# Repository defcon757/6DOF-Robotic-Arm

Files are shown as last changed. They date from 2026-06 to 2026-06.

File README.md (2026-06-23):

# ARM-6 — 6DOF Wi-Fi Controlled Robotic Arm

A fully remote-controlled, 6-degree-of-freedom robotic arm with live ESP32-CAM video feedback, controlled through a locally hosted Python/Flask web GUI over Wi-Fi.

Built by **Aidan Hernandez** — ENG GEN 101, Spring 2026.

---

## 📸 System Overview

```
Operator (Browser GUI)
        │
        ▼
Python Flask Server (Laptop)
   ├── Sends motion commands → ESP32 (ARM CONTROLLER)
   │                                   └── PCA9685 → 7 motors
   └── Streams video from  ← ESP32-CAM (CAMERA)
```

The system uses **two separate ESP32 boards**:
- `esp32_arm_controller` — receives JSON commands over HTTP, drives all 7 motors via a PCA9685 servo driver
- `esp32_cam_streamer` — streams MJPEG video from the OV2640 camera sensor over HTTP

---

## 🤖 Hardware

| Component | Qty | Notes |
|---|---|---|
| ESP32 Dev Board | 1 | Arm controller |
| ESP32-CAM (AI Thinker) | 1 | Video stream |
| PCA9685 16-Channel Servo Driver | 1 | I2C, drives all motors |
| REV Robotics HD Hex Motor (Continuous) | 3 | Base (×1), Shoulder (×2, mirrored) |
| MG996R Servo | 2 | Elbow, Wrist U/D |
| Micro Servo | 2 | Wrist Rotation, Claw |
| 5V 20A Power Supply | 1 | Powers motors + electronics |
| 3D Printed Arm Structure | — | See `/cad/stl/` |

### Motor Channel Map (PCA9685)

| Channel | Joint | Type |
|---|---|---|
| 0 | Base | Continuous motor |
| 1 | Left Shoulder | Continuous motor |
| 2 | Right Shoulder | Continuous motor (mirrored) |
| 3 | Elbow | Positional servo |
| 4 | Wrist Up/Down | Positional servo |
| 5 | Wrist Rotation | Positional servo |
| 6 | Claw | Positional servo |

### PWM Reference (50 Hz)

| Value | Meaning |
|---|---|
| `102` | Full reverse (continuous motors) |
| `307` | Stop / center (CONT_STOP) |
| `512` | Full forward (continuous motors) |
| `102–512` | Mapped from 0°–270° (positional servos) |

---

## 🗂 Repository Structure

```
arm6-robot/
├── firmware/
│   ├── esp32_arm_controller/
│   │   └── esp32_arm_controller.ino   # ESP32 arm command receiver
│   └── esp32_cam_streamer/
│       └── esp32_cam_streamer.ino     # ESP32-CAM MJPEG stream server
│
├── server/
│   ├── app.py                         # Flask routes
│   ├── arm_controller.py              # RobotArm class — state + HTTP send
│   ├── arm_sequence.py                # Scripted sequences (wave, scan, pickup…)
│   ├── config.py                      # IP addresses
│   ├── templates/
│   │   └── index.html                 # Jinja2 dashboard template
│   └── static/
│       ├── script.js                  # Hold-to-move button logic, status polling
│       └── style.css                  # Dark dashboard theme
│
├── cad/
│   └── stl/                           # 3D-printable arm parts (upload .stl files here)
│       ├── Arm_Parts.stl
│       ├── Base_Parts.stl
│       ├── Claw_Parts.stl
│
├── docs/
│   ├── wiring_diagram.md
│   ├── setup_guide.md
│   └── images/                        # Photos / diagrams (upload here)
│
├── requirements.txt
├── .gitignore
└── README.md
```

---

## ⚡ Quick Start

### 1. Configure IPs

Edit `server/config.py`:
```python
ARM_IP    = "192.168.x.xxx"   # IP of the ESP32 arm controller
CAMERA_IP = "192.168.x.xxx"   # IP of the ESP32-CAM
```

### 2. Flash the ESP32 boards

- Open `firmware/esp32_arm_controller/esp32_arm_controller.ino` in Arduino IDE
- Open `firmware/esp32_cam_streamer/esp32_cam_streamer.ino` in Arduino IDE
- Update `ssid` and `password` in **both** sketches
- Flash each to the correct board (see [Setup Guide](docs/setup_guide.md))

### 3. Install Python dependencies

```bash
pip install -r requirements.txt
```

### 4. Start the Flask server

```bash
cd server
python app.py
```

### 5. Open the GUI

Navigate to `http://localhost:5000` in any browser on the same network.

---

## 🎮 Controls

### Continuous Motors (Base, Shoulder)
Hold a direction button — each tick nudges the PWM pulse by ±8 counts. Releasing the button sends a stop command that resets the pulse to `307` (CONT_STOP).

### Positional Servos (Elbow, Wrist U/D, Wrist Rotation, Claw)
Hold a direction button — each tick moves the servo ±15°. Range is clamped to 0°–270°. A CENTER button snaps the joint to 135°.

### Preset Sequences (CLI — `arm_sequence.py`)
Run standalone from the command line, bypasses Flask and sends directly to the ESP32:

```bash
cd server
python arm_sequence.py
```

| Key | Sequence |
|---|---|
| `1` | Wave |
| `2` | Scan (base sweep) |
| `3` | Pickup simulation |
| `4` | Wrist display |
| `5` | Full showcase |
| `6` | Idle loop |
| `0` | Home all joints |

---

## 📡 API Reference

All endpoints are POST (except `/status`), expect and return JSON.

| Route | Method | Body | Description |
|---|---|---|---|
| `/servo` | POST | `{name, delta}` | Relative servo move |
| `/servo_set` | POST | `{name, angle}` | Absolute servo position |
| `/motor_nudge` | POST | `{name, delta}` | Nudge continuous motor pulse |
| `/motor_stop` | POST | `{name}` | Stop a motor (reset to 307) |
| `/home` | POST | — | Center all joints |
| `/stop` | POST | — | Emergency stop all motors |
| `/status` | GET | — | Returns current servo angles + motor pulses |

Valid `name` values: `base`, `shoulder`, `elbow`, `wrist_ud`, `wrist_rotate`, `claw`

---

## 🖨 CAD / 3D Printing

The arm was designed in **Onshape**. All printable parts are in `cad/stl/`. Recommended print settings:
- Material: PLA or PETG
- Infill: 20–30%
- Supports: Required for base only

## ⚠️ Known Limitations

- Requires a stable 2.4 GHz Wi-Fi network (ESP32 does not support 5 GHz)
- Continuous motors use open-loop control — no positional feedback
- Power supply must be external (5V, ≥10A recommended for full motion)
- Camera stream is low resolution (160×120) to reduce latency

---

## 📄 License

MIT License — free to use, modify, and build upon.

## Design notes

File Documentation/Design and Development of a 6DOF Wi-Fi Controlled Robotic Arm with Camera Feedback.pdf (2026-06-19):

Hernandez 1

Design and Development of a 6DOF Wi-Fi Controlled Robotic Arm with Camera Feedback

Aidan Hernandez

Professor Parvaneh Ghaforyfard

ENG GEN 101

29 May 2026

Introduction

The purpose of this project was to design and build a robotic arm that could be controlled

remotely through Wi-Fi via a GUI and stream live camera feedback. The project was a

combination of mechanical design, mechatronics, and software development into a single

working prototype. The final system was designed using the engineering design process and is

intended to solve the problem of taking off a finished 3D printed object from the print bed so I

can remotely print another object while being away from home. However, I have applied a real-

world use case of technology to solve the problem of inspecting dangerous equipment by making

this process remote and automated.

Engineering Design Process

The engineering design process began by identifying the problem. In many real-world

situations, a person may need to move an object, inspect a space, or interact with equipment

without standing directly next to it due to a variety of reasons. This can be useful in

manufacturing, education, hazardous industrial environments, and remote operations. A robotic

arm is a practical solution because it can reproduce controlled motion or be operated live while

keeping the operator safe. My background research focused on robotic arm structures, servo and

continuous motor control, Wi-Fi communication, and camera-based remote operations. Existing

systems were reviewed to understand how robotic arms are powered, how motion is controlled,

and how feedback is provided to the user. This included looking into robotic arms controlled by

stepper motors and DIY projects done by others such as the PAROL 6; an open-source robotic

arm that can be ordered as a kit. Research also included the use of ESP32 microcontrollers,

which integrate Wi-Fi and Bluetooth capability in a compact embedded platform (Espressif), and

the PCA9685 servo driver board, which can control up to 16 servo channels over I2C with only two signal pins (Adafruit, “Overview”). After researching the problem, several solutions were

considered. A wired robotic arm was one option; however, it would have limited remote

capabilities when compared to a Wi-fi or Bluetooth controlled arm. A Bluetooth solution was

also considered, but Wi-Fi was selected because it allowed the system to run through a locally

hosted laptop server and made it easier to separate the camera's feed from the control commands.

The final design used a Python-based GUI (graphical user interface), an ESP32- CAM for

video streaming, and a separate ESP32 for receiving arm commands. The robotic arm was

designed on Onshape as a 6 degree of freedom system and programming for the Flask server

locally hosted on a laptop through PyCharm. The structure was modeled to match the arm’s

physical movement requirements and to keep the assembly compact and printable. The final

design used seven motors total: three REV Robotics continuous motors, two MG996R servo

motors, and two micro servo motors. The motors were assigned to the base, shoulder, elbow,

wrist, and claw functions. This arrangement was chosen in accordance with the inverse

kinematics from a robotic arm simulator on the GeoGebra website made by Oscar Arcera López.

The prototype was built using the 3D-printed arm parts, the ESP32-CAM with antenna, a

separate ESP32 development board, a PCA9685 servo driver, and a 5V 20A external power

supply. The power supply was necessary because the motors and electronics required more

current than a microcontroller USB port could safely provide. The ESP32 board handled the

command side of the system, while the ESP32-CAM handled the video side. The Python GUI,

built in PyCharm, displayed the camera feed on the left and arm controls on the right, allowing

the user to monitor and operate the arm from one screen.

Testing and evaluation were completed by checking Wi-Fi connection stability, live

video streaming, motor response, and full arm motion. The arm successfully responded to control inputs, and the camera feed allowed the operator to see the movement in real time. During

testing, some of the main weaknesses involved power distribution, synchronization between

multiple motors, and mechanical alignment of joints. These issues were addressed through

adjustment, calibration, and redesign of the mounting positions. Future improvements could

include stronger motors, better cable management, battery-powered portability, and additional

sensors for autonomous movement. A mobile app version of the control system would also make

the project easier to use and more flexible in a demonstration setting.

Technical Discussion

The system works by separating visual feedback from control communication. The

ESP32-CAM streams video to the locally hosted Python server, and the second ESP32 receives

movement commands from the same server. The Python program serves as the central interface

between the operator and the hardware. When the user presses a control on the GUI, the program

sends a command to the ESP32. The ESP32 then forwards the motion request to the PCA9685

driver, which generates the PWM signals needed to control the motors.

PWM, or pulse width modulation, is important because it allows the controller to send

position or motion instructions using timed electrical pulses. This is the standard method used by

many servo systems. The PCA9685 driver is especially useful because it offloads the repetitive

signal generation from the microcontroller and can manage many output channels at once. In this

project, that made it easier to support multiple motors without overloading the controller. The

use of a separate camera board also reduced complexity because the video stream could be

handled independently from the arm motion commands.

The project has several real-world applications. A system like this could be adapted for

basic laboratory automation, hazardous handling, object inspection, or educational robotics

demonstrations. It also reflects the type of system integration used in larger robotic platforms,

where mechanical motion, embedded control, and operator feedback must all work together. The

main advantage of the design is that it is low cost, modular, and easy to expand. The main

limitations are that it depends on a stable Wi-Fi connection, requires a strong external power

supply, and is limited by the torque and precision of the motors used.

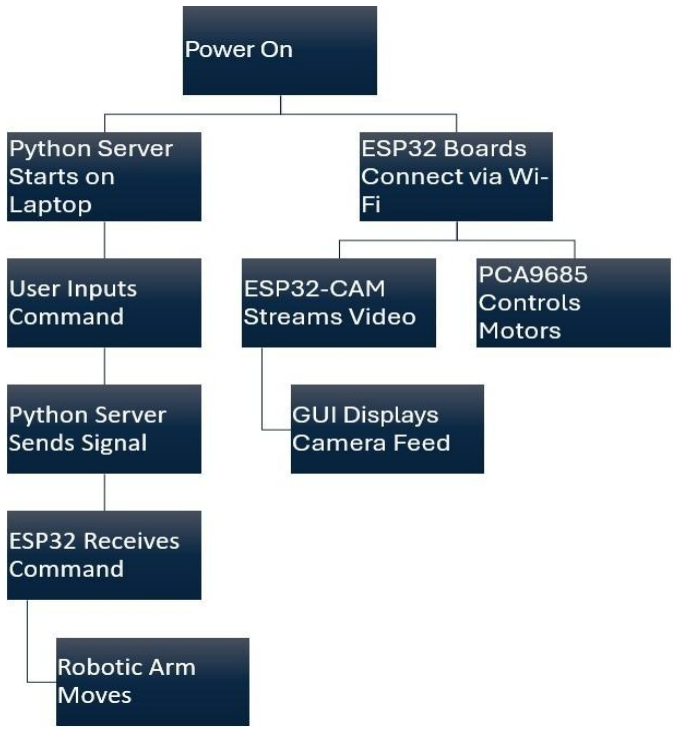
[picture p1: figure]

Results and Discussion

The final project accomplished the main goal of creating a remotely controlled robotic

arm with live camera feedback. The arm was designed, modeled, assembled, and operated as a functional prototype. The Python GUI provided a practical way to control the arm, and the

ESP32-CAM provided the operator with a live view of the workspace. The result was a system

that demonstrated the engineering design process from problem definition through testing and

redesign.

Several challenges were encountered during development. One challenge was ensuring

that the motors received enough current without causing the microcontrollers to reset. Another

challenge was mechanical alignment since the arm parts had to be positioned carefully for the

joints to move correctly. The most important lesson learned was that hardware and software must

be developed together. Even if the code is correct, the system will not work well if the

mechanical design is weak, or the power supply is undersized. Likewise, a strong mechanical

design still requires reliable software and communication to function.

Overall, the project was successful because it met the main design objectives and

demonstrated multiple engineering concepts in one system. It showed how CAD design,

embedded systems, wireless communication, and prototype testing can be combined into an

engineering solution. The project also showed that iteration is an important part of engineering

since improvements were made after testing revealed specific weaknesses.

Conclusion

This project successfully developed a 6DOF Wi-Fi controlled robotic arm with camera

feedback using Onshape modeling, ESP32-based communication, a PCA9685 servo driver, a

Python GUI, and an external high-current power supply. The arm was built as an integrated system that could receive wireless commands, stream live video, and move multiple joints in a

coordinated way. The final design demonstrated both the technical and practical value of the

engineering design process. The importance of the project was not only in building a robotic

arm, but also in showing how engineering problems are solved through research, testing, and

redesign. The process made it clear that successful engineering depends on balancing

performance, cost, power, and usability. In the end, the project provided a strong example of how

science, engineering, and technology can be combined to create a working solution to a real

problem.

Works Cited

Adafruit. “Overview.” Adafruit PCA9685 16-Channel Servo Driver, Adafruit Learning System, 16 Oct. 2012, learn.adafruit.com/16-channel-pwm-servo-driver/overview. Accessed 29
May 2026. [Design and...edback (1) | PDF] (https://studentlaccd-my.sharepoint.com/personal/hernana1827_student_laccd_edu/Documents/Microsoft%20Copilot%20Chat%20Files/Design%20and%20Development%20of%20a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)

Arcera López, Oscar. “Robotic Arm Simulation.” GeoGebra, www.geogebra.org/m/fsq5cjag. Accessed 29 May 2026. [learn.adafruit.com] (https://learn.adafruit.com/16-channel-pwm-servo-driver/overview)

Espressif Systems. “ESP32 Wi-Fi & Bluetooth SoC.” Espressif Systems, www.espressif.com/en/products/socs/esp32. Accessed 29 May 2026. [geogebra.org] (https://www.geogebra.org/m/fsq5cjag)

JetBrains. “PyCharm: The Only Python IDE You Need.” JetBrains, www.jetbrains.com/pycharm/. Accessed 29 May 2026. [espressif.com] (https://www.espressif.com/en/products/socs/esp32)

MLA Handbook. 9th ed., Modern Language Association of America, 2021.

Modern Language Association. “MLA Style Center.” Modern Language Association, style.mla.org/. Accessed 29 May 2026.

Onshape. “Onshape Product Development Platform.” Onshape, www.onshape.com/en/. Accessed 29 May 2026. [jetbrains.com] (https://www.jetbrains.com/pycharm/)

Pallet Projects. “Welcome to Flask.” Flask Documentation, flask.palletsprojects.com/. Accessed 29 May 2026. [onshape.com] (https://www.onshape.com/en/)

Python Software Foundation. “Python Documentation.” Python, www.python.org/doc/. Accessed 29 May 2026.

REV Robotics. “HD Hex Motor 40:1 Spur Gearbox.” REV Robotics, www.revrobotics.com/rev-41-1301/. Accessed 29 May 2026. [flask.pall...ojects.com] (https://flask.palletsprojects.com/)

Source Robotics. “PAROL6 Docs.” PAROL6 Documentation, source-robotics.github.io/PAROL-docs/. Accessed 29 May 2026. [revrobotics.com] (https://www.revrobotics.com/rev-41-1301/)

Tower Pro. “MG996R.” Tower Pro, towerpro.com.tw/product/mg996R/. Accessed 29 May 2026. [source-rob....github.io] (https://source-robotics.github.io/PAROL-docs/)

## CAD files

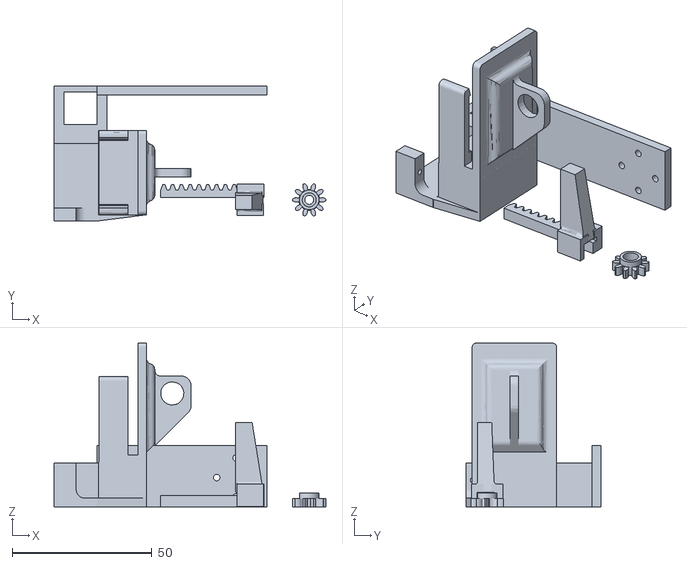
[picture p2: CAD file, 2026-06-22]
CAD/Claw_Part.stl
97.2 x 48.3 x 58.5

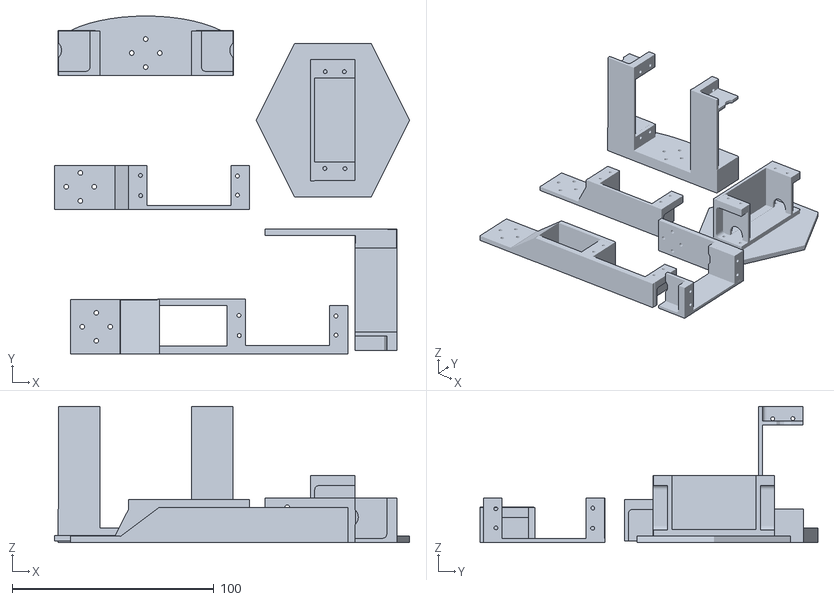
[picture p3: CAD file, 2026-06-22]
CAD/Arm_Parts.stl
176.3 x 167.7 x 67.6

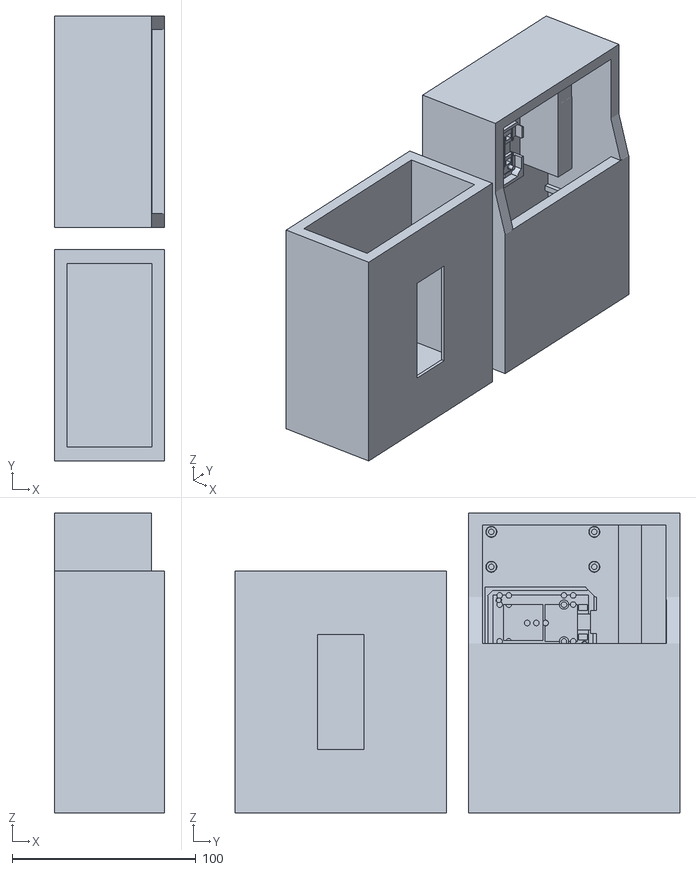
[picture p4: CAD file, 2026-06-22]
CAD/Base _Parts.stl
60.0 x 242.0 x 163.0

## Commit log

2026-06-19 Revise README for 6DOF Robotic Arm project
    Updated project title and expanded README with detailed features, hardware, software, system architecture, setup instructions, controls, and future improvements.
2026-06-19 Update servo types for wrist rotation and claw
2026-06-19 Create ESP32_CAM_Stream.ino
2026-06-22 Rename PXL_20260526_071529286.MP.jpg to Full Arm One
2026-06-22 Rename PXL_20260526_071415230.jpg to Top Arm View
2026-06-22 Rename PXL_20260526_071602538.jpg to Full Arm Two
2026-06-22 Rename PXL_20260526_071506534.jpg to Mount Power Supply
2026-06-23 Revise 3D printing settings and STL file note
    Updated print settings for CAD parts and clarified STL file handling.
